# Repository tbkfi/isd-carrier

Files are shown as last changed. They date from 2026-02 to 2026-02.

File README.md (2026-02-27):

# Prototype PCB for International Sensor Development Project

This repository contains a schematic and pcb design for an international sensor development project between Metropolia UAS and Osnabrück Hochschule, which concluded on 2026.02.27.

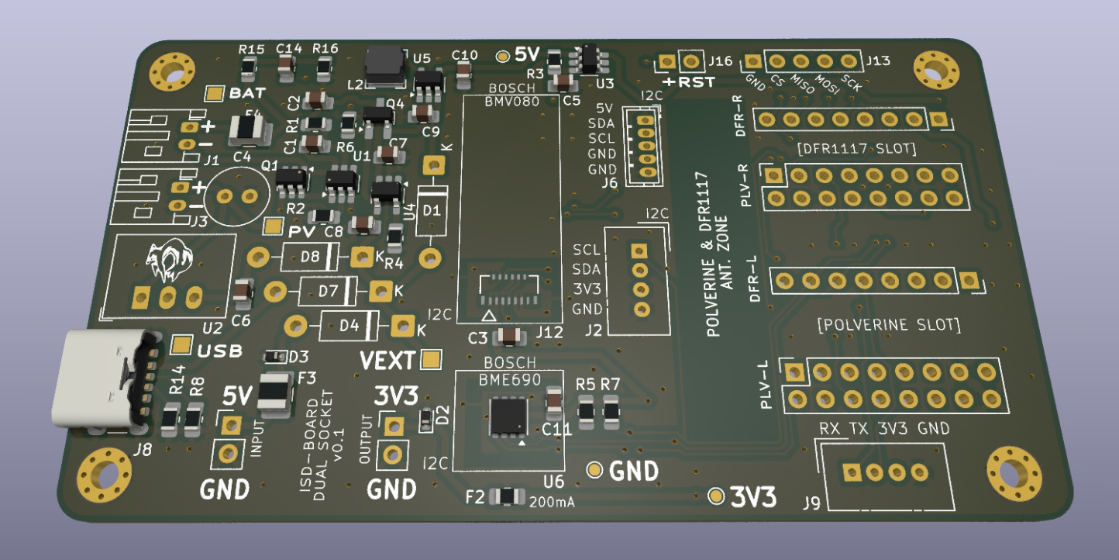
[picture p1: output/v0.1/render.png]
ISD Carrier Prototype PCB Render


## Board Features

The PCB provides 5V power to the MCU modules, which have built-in LDOs to provide 3V3 power
for external and integrated peripherals.

- Interleaved dual socket (BlackIoT Polverine and DFR1117)
- Built-in power switch (external reset/power button)
- LiPo protection circuit (2.4-4.2V)
- LiPo charging circuit (configurable output)
- Power Path management using P-FET, actuated by external power voltage to disconnect battery from load during charging.
- Auxiliary 3V3 output pin header.
- Multiple power input options (all selectively populatable):
	- JST(2.0mm): LiPo battery
	- JST(2.0mm): Photovoltaic panel (8-28V)
	- Header(2.54mm): E.g. Bench-top power supply
    - PCB USB-C (charging, 5V peripherals, main power)
	- (MCU module USB-C (no 5V peripherals, no charging!))
- Sensor support (for both Polverine & DFR1117):
	- BME690 via I2C (integrated, LGA, 3V3)
	- BMV080 via I2C (integrated, ZIF-connector, 3V3)*
	- Seeed E5 LoRa via UART (external, Grove, 3V3)
	- SPS30 via I2C (external, ZHR-5, 5V)
	- I2C (external, Grove, 3V3)
	- SPI (Header: CS, MISO, MOSI, SCK, GND)

## Documentation

See the repository directory labeled 'output' for the board revision files. The directory contains schematic (pdf), routing (png), and an interactive bill of materials (bom).

ISD Carrier Prototype PCB Schematic

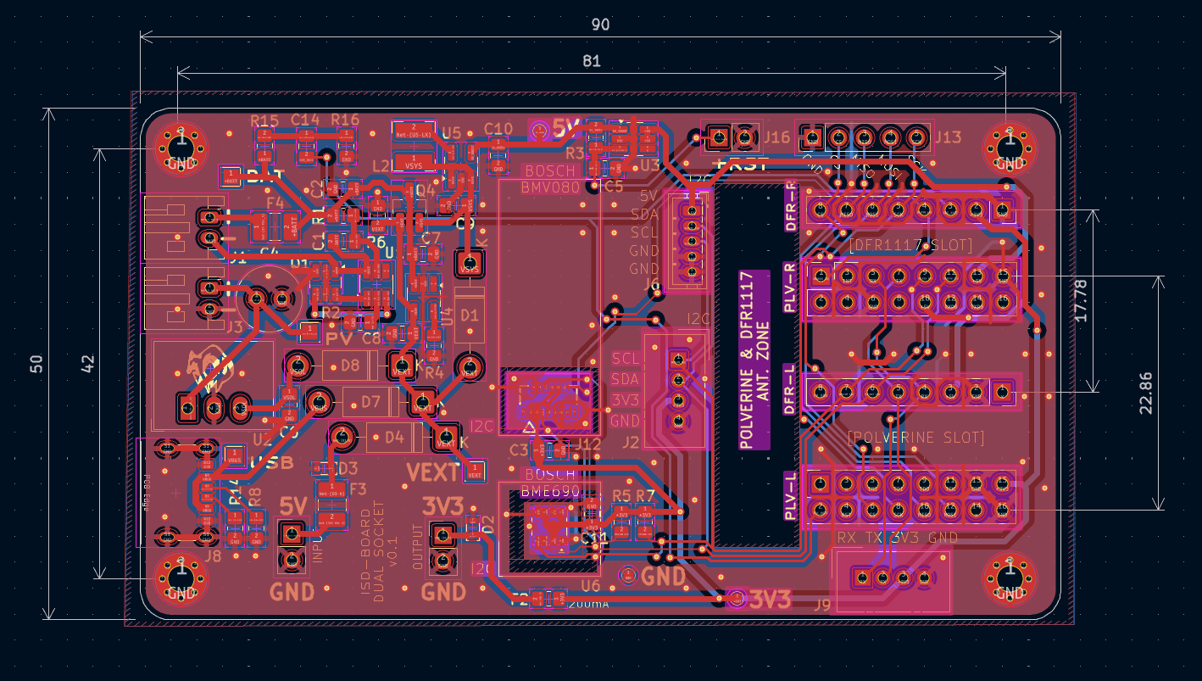
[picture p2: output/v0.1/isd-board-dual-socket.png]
ISD Carrier Prototype PCB Routing


### Issues

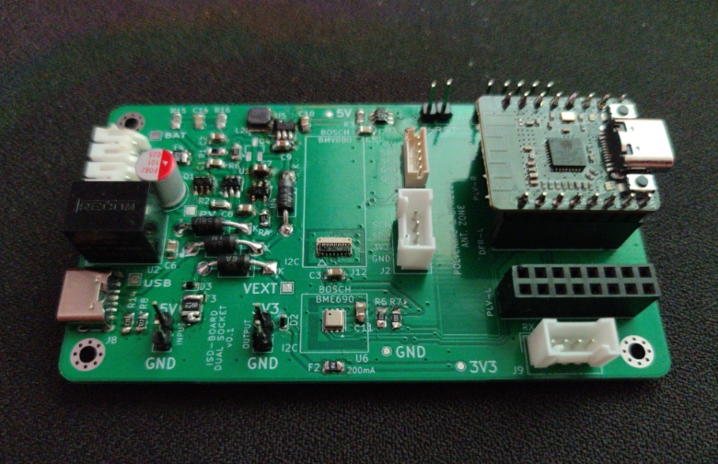
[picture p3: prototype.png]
Physical ISD Carrier Prototype PCB


This section contains issues encountered up to and during the final integration testing when using
this board with all the external peripherals. Some issues are PCB related, others are practical inefficiencies or overlooked details.

### version 0.1
1. ZIF-connector: Insertion direction is reversed. Causing the pin-direction to be flipped, making the connector unusable. Neccessitates the use of Polverine for BMV080 functionality.
2. Power Path: P-FET which was ordered had differing package type from original. Soldering was still possible at 45deg angle, and bending unneeded pins above the package to avoid shorts.
3. DW01A: Behaviour was unexpected during testing despite following datasheet application diagram in design. Couple workarounds were found, but ultimately the IC should be replaced in the design
with something more robust from TI or Microchip (E.g.) to increase reliability and control over the protection circuit.
4. Peripheral cabling: Operation was susceptible to jumpers, badly crimped or soldered cables, which caused unnecessary debugging and inconsistent results.
5. Prototype PCB count: Not enough prototypes were made to provide such large teams with an efficient number of PCBs while continuing to validate power management behaviour.
As LoRa and Sensor teams received one prototype, and found them to be in working condition, it became virtually impossible to get either of them back for more power-related validation. 
6. It's a good idea to validate the MCU modules and cabling that is in use by other teams, specially if they were made or modified by them, as on more than one ocassion incorrectly (or not at all)
soldered pin headers caused certain functionality to not work, as nothing was plugged in...
7. I2C Pull-ups: Existing 10k pulls caused issues with DFR1117, while the configuration worked with Polverine. The pull-ups on PCB were removed to fix the issue. Though it's possible
this issue was due to bad cabling or bad sensor, as the pull-ups shouldn't technically cause this kind of issue in this configuration.

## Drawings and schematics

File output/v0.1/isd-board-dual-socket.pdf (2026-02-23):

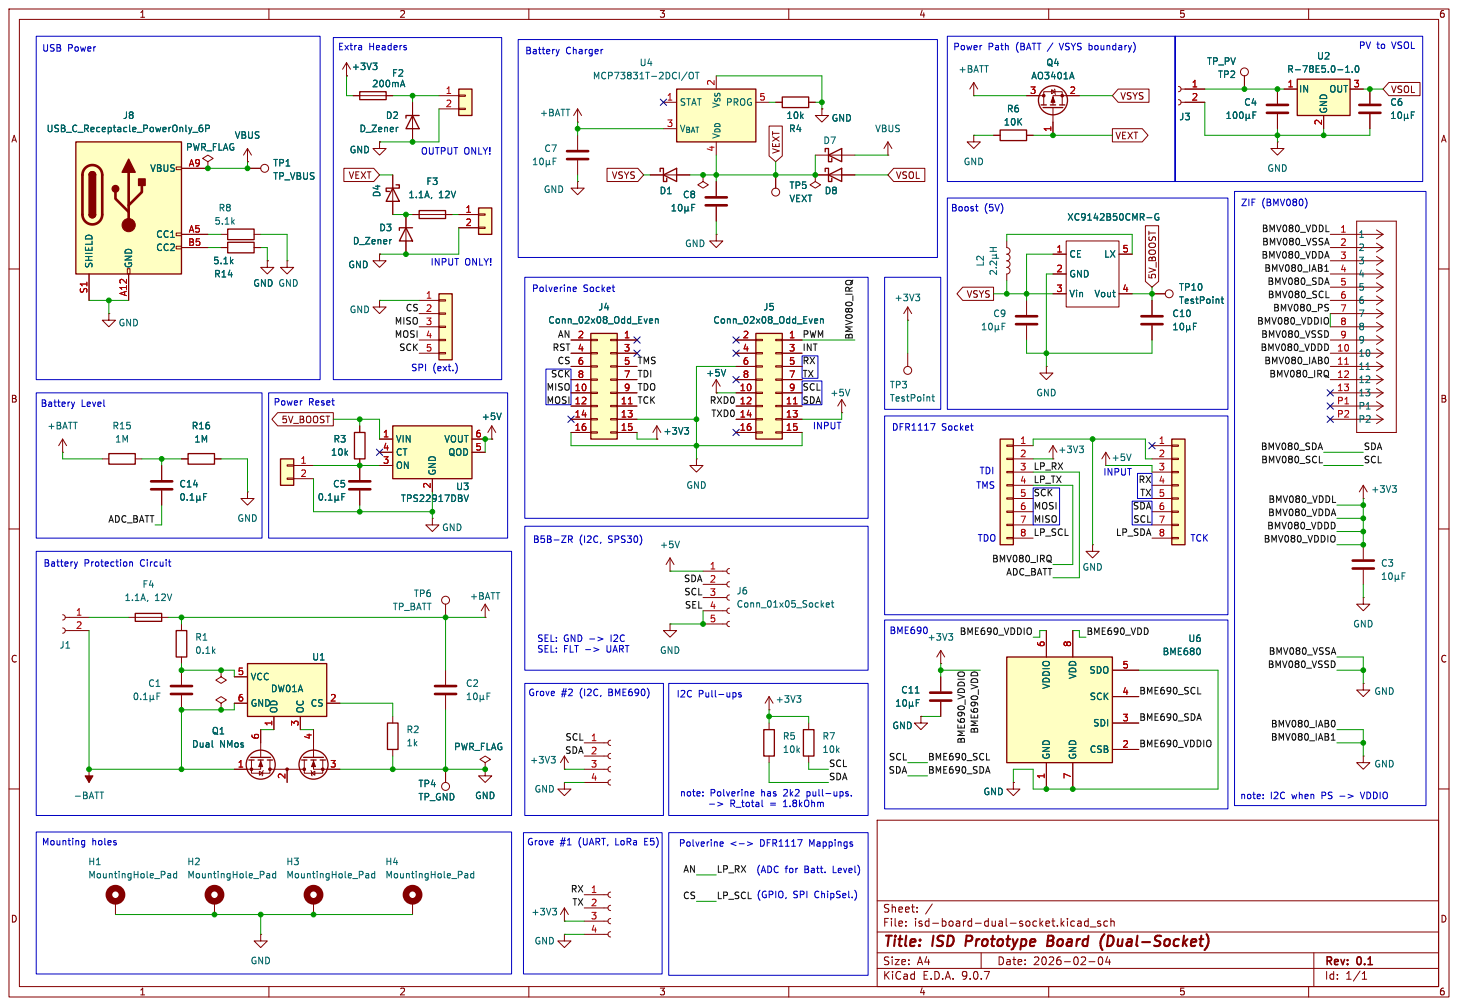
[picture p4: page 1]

7 SDO 5 SCK 4 SDI 3 CSB 2 U6 BME680 GND GND GND

7 SDO 5 SCK 4 SDI 3 CSB 2 GND

(ADC for Batt. Level)

Id: 1/1 Title: ISD Prototype Board (Dual-Socket) File: isd-board-dual-socket.kicad_sch Sheet: /

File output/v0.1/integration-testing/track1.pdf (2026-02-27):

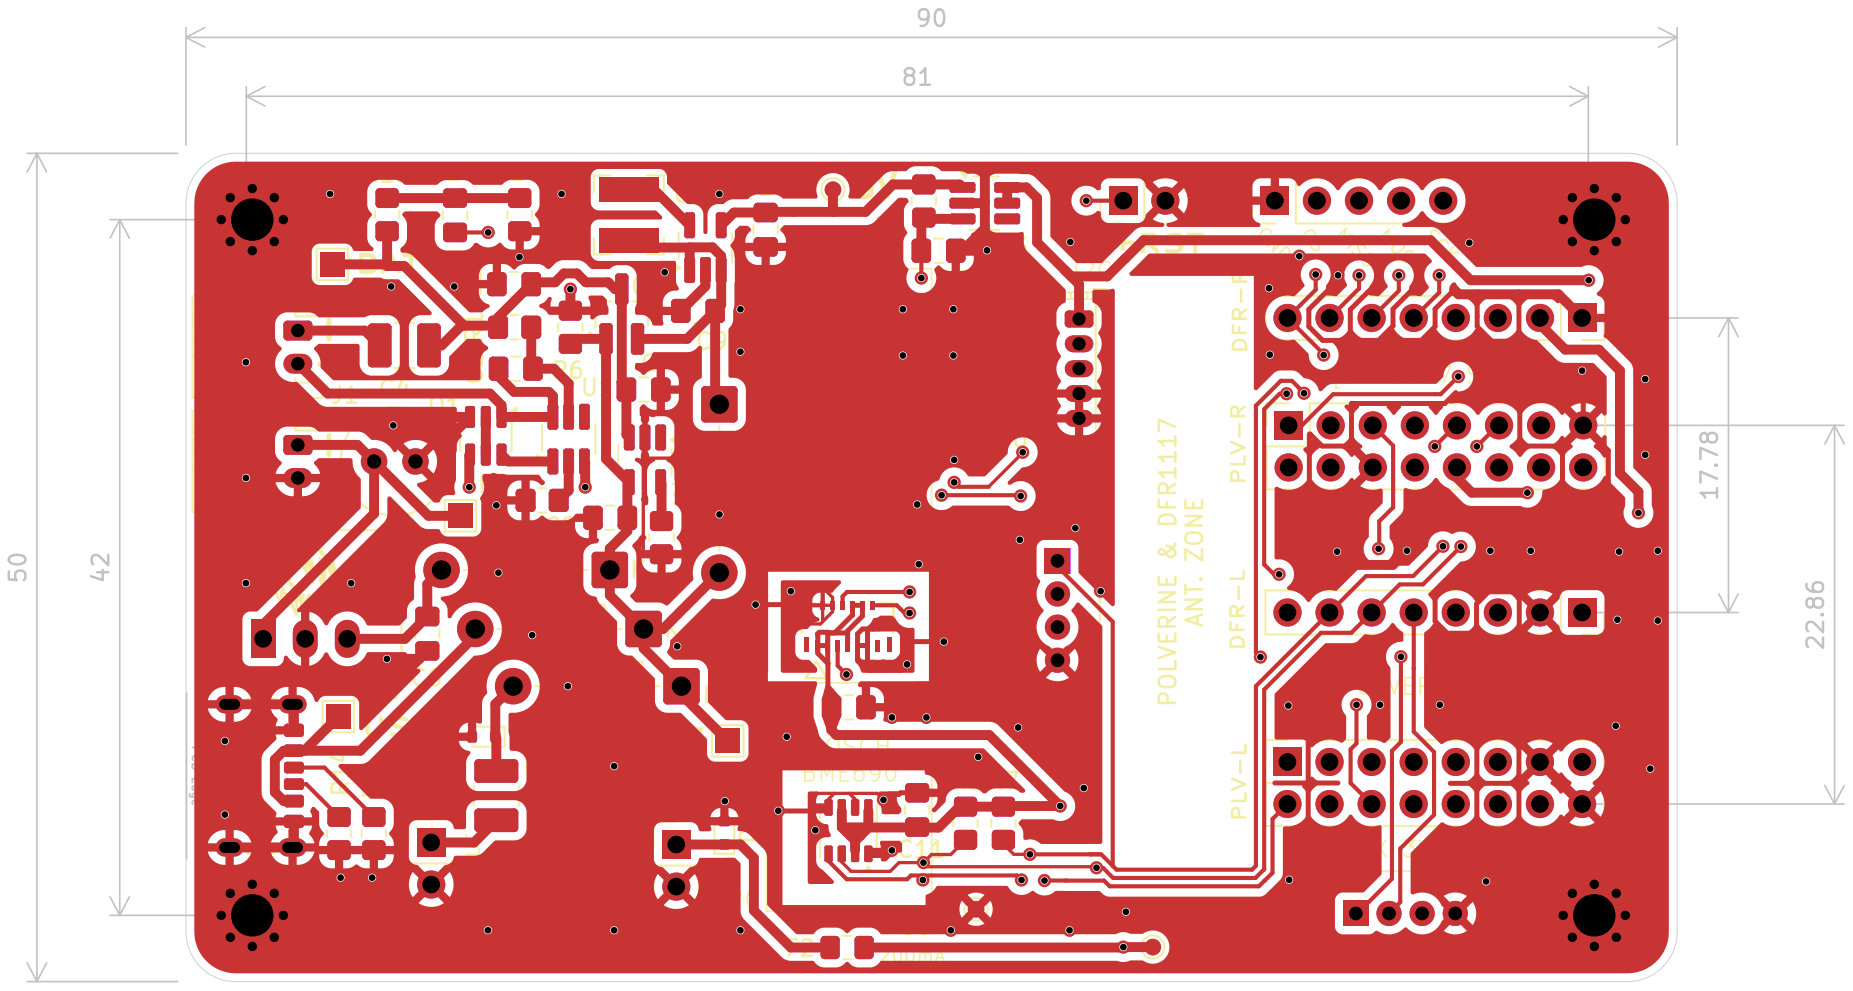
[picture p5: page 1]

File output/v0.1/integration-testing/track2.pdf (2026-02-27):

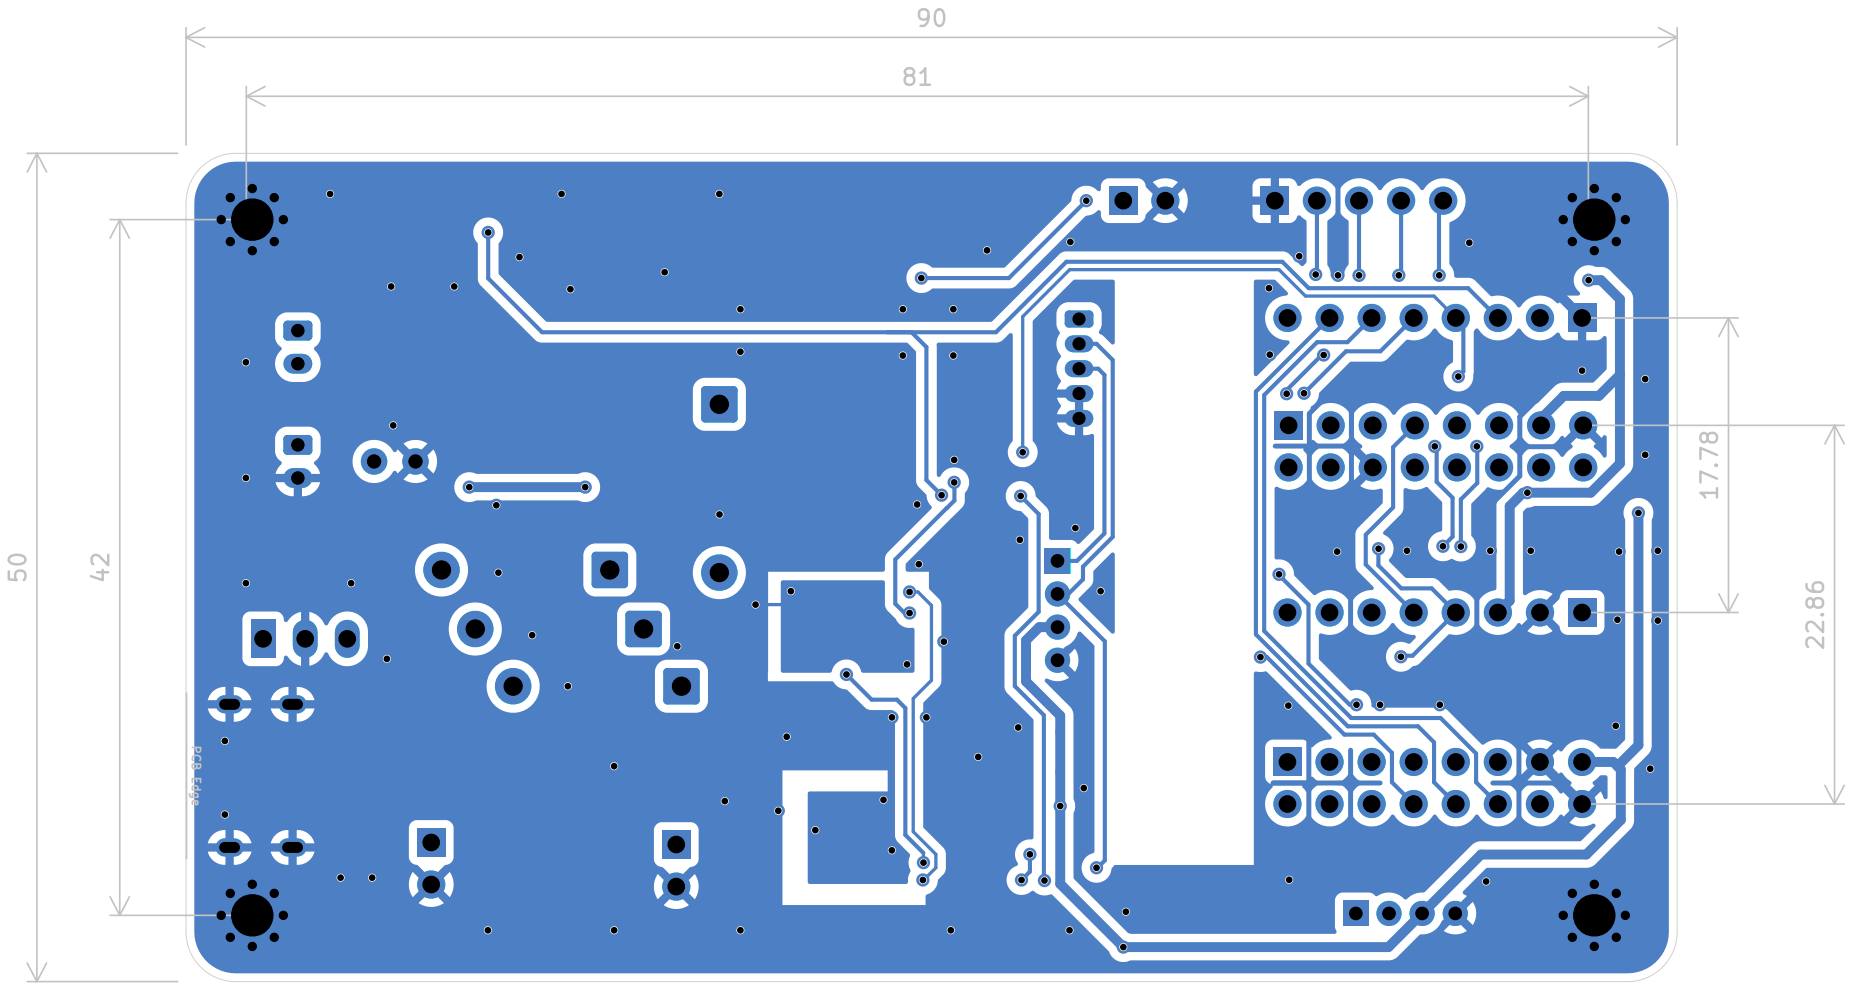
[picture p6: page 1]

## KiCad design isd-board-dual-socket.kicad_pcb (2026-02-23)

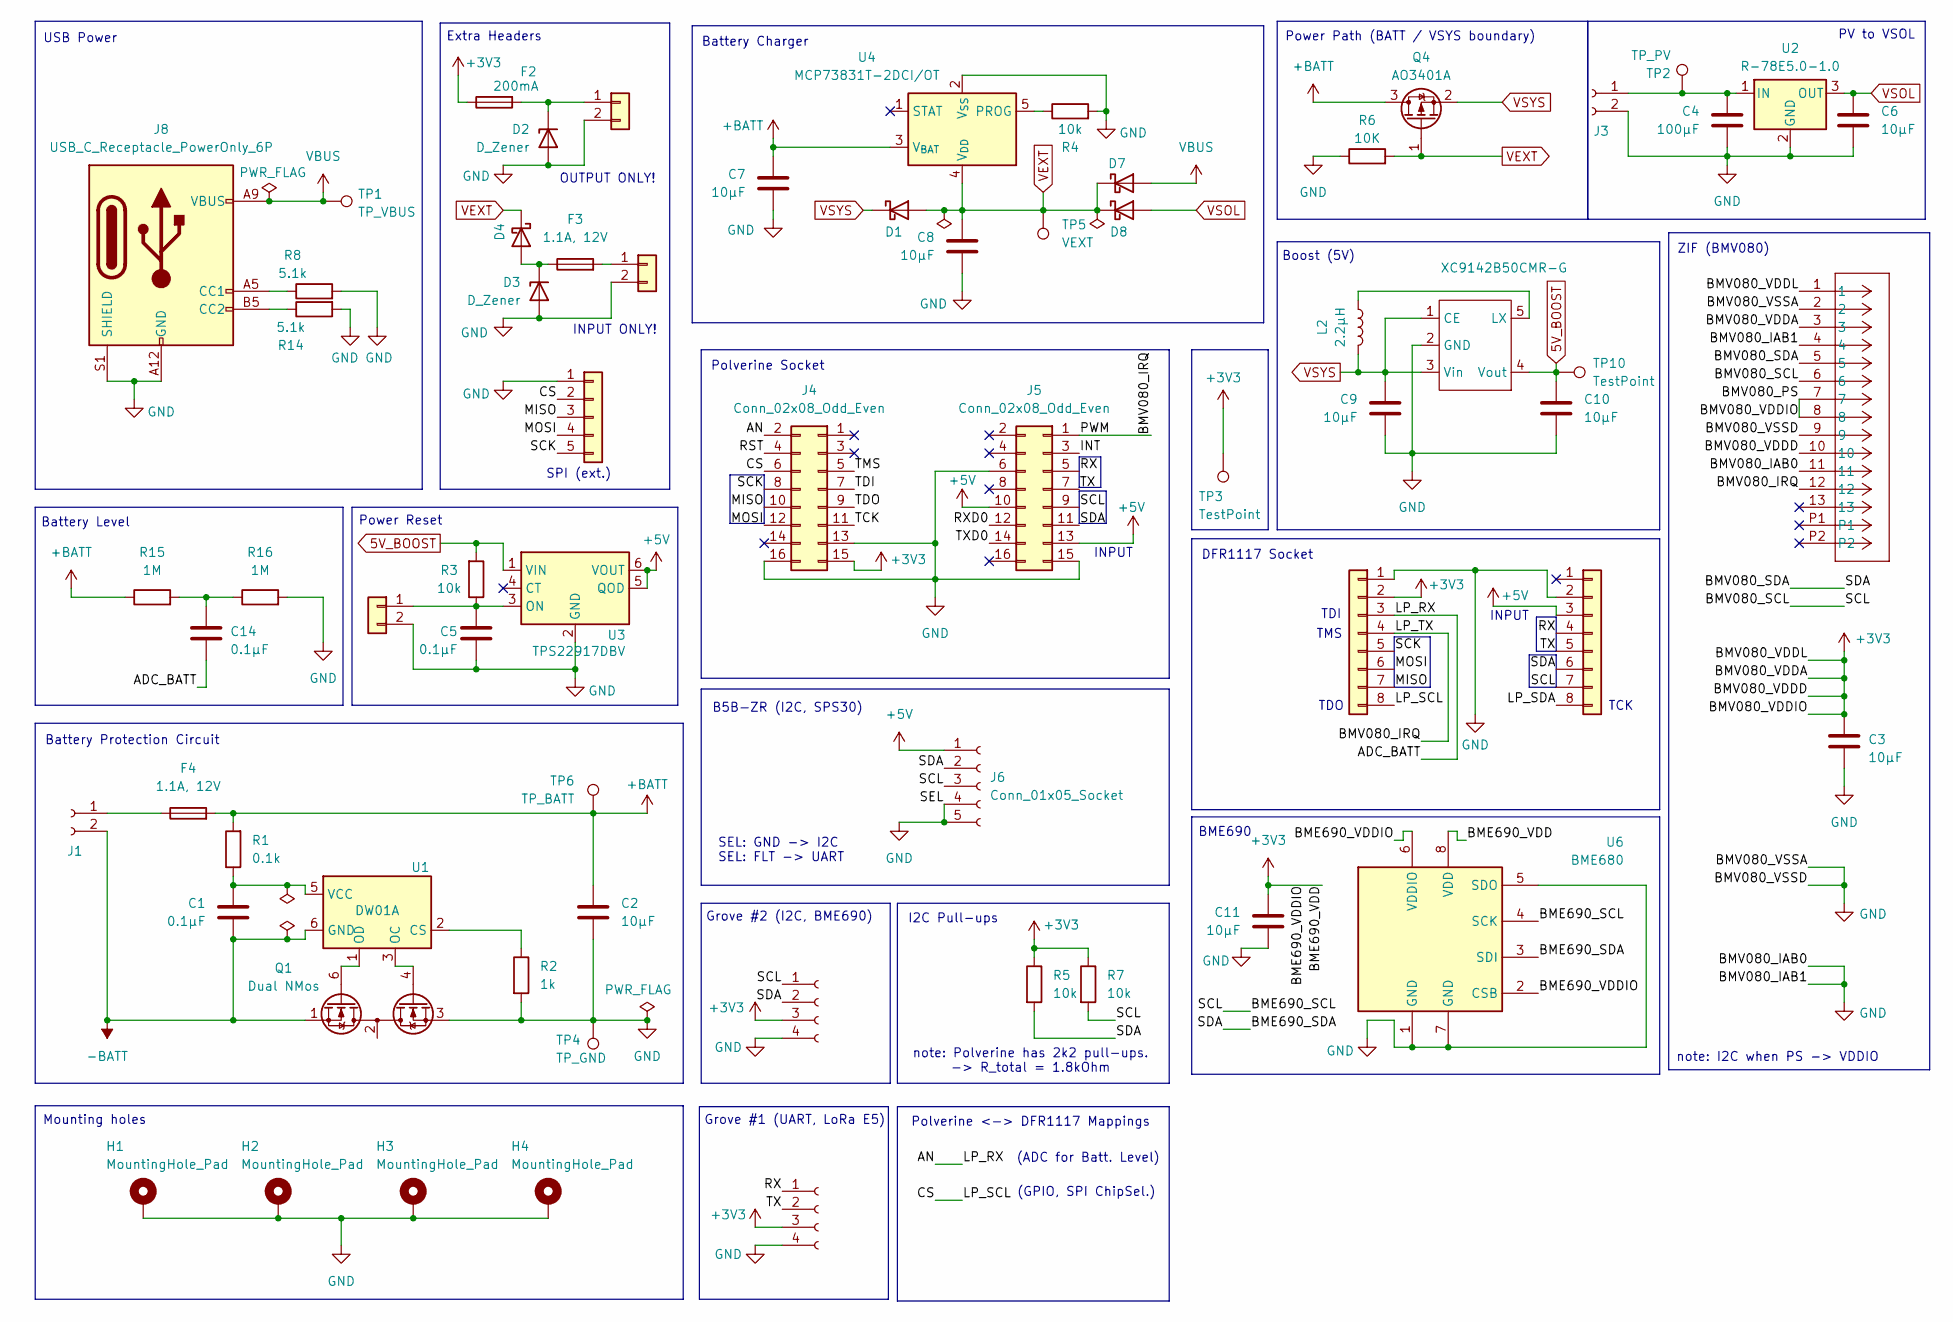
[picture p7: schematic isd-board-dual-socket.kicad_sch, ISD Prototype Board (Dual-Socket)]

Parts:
C1, C5, C14: 0.1µF; C_0805_2012Metric_Pad1.18x1.45mm_HandSolder; MPN 399-C0805C104K5RACTUCT-ND
C2, C3, C6, C7, C8, C9, C10, C11: 10µF; C_0805_2012Metric_Pad1.18x1.45mm_HandSolder; MPN GRM21BR61E106KA73K
C4: 100µF; C_Radial_D6.3mm_H11.0mm_P2.50mm; MPN RPF0608101M035K
D1, D4, D7, D8: D_Schottky; D_DO-41_SOD81_P10.16mm_Horizontal; MPN 1655-1N5817CT-ND
D2, D3: D_Zener; D_SOD-523; MPN CPDH5V0U
F2: 200mA; Fuse_0805_2012Metric_Pad1.15x1.40mm_HandSolder; MPN SMD0805B020TF
F3, F4: 1.1A, 12V; Fuse_1210_3225Metric_Pad1.42x2.65mm_HandSolder; MPN SMD1210B110TF
H1, H2, H3, H4: MountingHole_Pad; MountingHole_2.5mm_Pad_Via; MPN none
J1, J3: Conn_01x02_Socket; JST_PH_S2B-PH-K_1x02_P2.00mm_Horizontal; MPN 455-1719-ND
J2, J9: Conn_01x04_Socket; NS-Tech_Grove_1x04_P2mm_Vertical; MPN 1597-1082-ND
J4, J5: Conn_02x08_Odd_Even; PinSocket_2x08_P2.54mm_Vertical; MPN 732-61301621821-ND
J6: Conn_01x05_Socket; JST_ZH_B5B-ZR_1x05_P1.50mm_Vertical; MPN B5B-ZR
J7, J10: Conn_01x08; PinSocket_1x08_P2.54mm_Vertical; MPN PPTC081LFBN-RC
J8: USB_C_Receptacle_PowerOnly_6P; USB_C_Receptacle_GCT_USB4125-xx-x-0190_6P_TopMnt_Horizontal; MPN USB4125-GF-A
J12: 5035661302; CON_5035661302_MOL; MPN 046844713002846+
J13: Conn_01x05; PinHeader_1x05_P2.54mm_Vertical; MPN ???
J14, J15, J16: Conn_01x02; PinHeader_1x02_P2.54mm_Vertical; MPN 61300211121
L2: 2.2µH; L_Bourns-SRN4018; MPN SRN4018-2R2M
Q1: Dual NMos; SOT-23-6; MPN DMG9926UDMDICT-ND
Q4: AO3401A; SOT-23_Handsoldering; MPN AO3401A
R1: 0.1k; R_0805_2012Metric_Pad1.20x1.40mm_HandSolder; MPN 541-100CCT-ND
R2: 1k; R_0805_2012Metric_Pad1.20x1.40mm_HandSolder; MPN 10-ERJ-HP6J102VCT-ND
R3, R4, R5, R7: 10k; R_0805_2012Metric_Pad1.20x1.40mm_HandSolder; MPN 541-4163-1-ND
R6: 10K; R_0805_2012Metric_Pad1.20x1.40mm_HandSolder; MPN 541-4163-1-ND
R8, R14: 5.1k; R_0805_2012Metric_Pad1.20x1.40mm_HandSolder; MPN 311-5.1KARCT-ND
R15, R16: 1M; R_0805_2012Metric_Pad1.20x1.40mm_HandSolder; MPN 408-RG2012P-105-B-T5CT-ND
TP1: TP_VBUS; TestPoint_Pad_1.5x1.5mm; MPN none
TP2: TP_PV; TestPoint_Pad_1.5x1.5mm; MPN none
TP3, TP10: TestPoint; TestPoint_Pad_D1.0mm; MPN none
TP4: TP_GND; TestPoint_Pad_D1.0mm; MPN none
TP5: VEXT; TestPoint_Pad_1.5x1.5mm; MPN none
TP6: TP_BATT; TestPoint_Pad_1.5x1.5mm; MPN none
U1: DW01A; SOT-23-6_Handsoldering; MPN DW01A
U2: R-78E5.0-1.0; Converter_DCDC_RECOM_R-78E-0.5_THT; MPN R-78E5.0-1.0
U3: TPS22917DBV; SOT-23-6_Handsoldering; MPN TPS22917DBV
U4: MCP73831T-2DCI/OT; SOT-23-5_HandSoldering; MPN MCP73831T-2DCI/OT
U5: XC9142B50CMR-G; SOT-23-5_HandSoldering; MPN XC9142B50CMR-G
U6: BME680; Bosch_LGA-8_3x3mm_P0.8mm_ClockwisePinNumbering; MPN BME690

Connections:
5V_BOOST: C10.1, R3.2, TP10.1, U3.1 (VIN), U5.4 (Vout)
+3V3: C3.1, C11.1, F2.1, J2.3, J4.15, J9.3, J10.2, J12.1, J12.3, J12.7, J12.8, J12.10, R5.1, R7.1, TP3.1, U6.2 (CSB), U6.6 (VDDIO), U6.8 (VDD)
+5V: J5.10, J5.13, J6.1, J7.3, U3.5 (QOD), U3.6 (VOUT)
+BATT: C2.1, C7.1, F4.2, Q4.3 (D), R1.2, R15.1, TP6.1, U4.3 (V_{BAT})
-BATT: C1.2, J1.2, Q1.1 (D1), U1.6 (GND)
/ADC_BATT: C14.2, J4.2, J10.3
/BME690_SCL: J2.1, J5.9, J6.3, J7.7, J12.6, R7.2, U6.4 (SCK)
/BME690_SDA: J2.2, J5.11, J6.2, J7.6, J12.5, R5.2, U6.3 (SDI)
/BMV080_IRQ: J5.1, J10.4, J12.12
/CS: J4.6, J10.8, J13.2
/INT: J5.3
/LP_SDA: J7.8
/MISO: J4.10, J10.7, J13.3
/MOSI: J4.12, J10.6, J13.4
/RST: J4.4
/RX: J5.5, J7.4, J9.1
/RXD0: J5.12
/SCK: J4.8, J10.5, J13.5
/TCK: J4.11
/TDI: J4.7
/TDO: J4.9
/TMS: J4.5
/TX: J5.7, J7.5, J9.2
/TXD0: J5.14
GND: C2.2, C3.2, C4.2, C5.2, C6.2, C7.2, C8.2, C9.2, C10.2, C11.2, D2.2 (A), D3.2 (A), H1.1, H2.1, H3.1, H4.1, J2.4, J3.2, J4.13, J4.16, J5.6, J5.15, J6.4, J6.5, J7.2, J8.A12 (GND), J8.B12 (GND), J8.S1 (SHIELD), J9.4, J10.1, J12.2, J12.4, J12.9, J12.11, J13.1, J14.2, J15.2, J16.2, Q1.3 (S2), R2.2, R4.2, R6.1, R8.2, R14.2, R16.2, TP4.1, U2.2 (GND), U3.2 (GND), U4.2 (V_{SS}), U5.2 (GND), U6.1 (GND), U6.5 (SDO), U6.7 (GND)
unnamed: C14.1, R15.2, R16.1
unnamed: D2.1 (K), F2.2, J14.1
unnamed: D3.1 (K), D4.2 (A), F3.1
unnamed: F4.1, J1.1
unnamed: C4.1, J3.1, TP2.1, U2.1 (IN)
unnamed: J8.A5 (CC1), R8.1
unnamed: J8.B5 (CC2), R14.1
unnamed: F3.2, J15.1
unnamed: C5.1, J16.1, R3.1, U3.3 (ON)
unnamed: Q1.6 (G1), U1.1 (OD)
unnamed: Q1.4 (G2), U1.3 (OC)
unnamed: Q1.2 (S1/D2), Q1.5 (S1/D2)
unnamed: R2.1, U1.2 (CS)
unnamed: C1.1, R1.1, U1.5 (VCC)
unnamed: R4.1, U4.5 (PROG)
unnamed: L2.2, U5.5 (LX)
VBUS: D7.2 (A), J8.A9 (VBUS), J8.B9 (VBUS), TP1.1
VEXT: C8.1, D1.2 (A), D4.1 (K), D7.1 (K), D8.1 (K), Q4.1 (G), R6.2, TP5.1, U4.4 (V_{DD})
VSOL: C6.1, D8.2 (A), U2.3 (OUT)
VSYS: C9.1, D1.1 (K), L2.1, Q4.2 (S), U5.1 (CE), U5.3 (Vin)

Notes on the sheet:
INPUT
B5B-ZR (I2C, SPS30)
Polverine Socket
TDO
I2C Pull-ups
PV to VSOL
Battery Level
OUTPUT ONLY!
Power Reset
INPUT ONLY!
note: Polverine has 2k2 pull-ups. -> R_total = 1.8kOhm
DFR1117 Socket
Mounting holes
TDI
BME690
(GPIO, SPI ChipSel.)
Boost (5V)
TCK
Power Path (BATT / VSYS boundary)
Extra Headers
(ADC for Batt. Level)
Battery Charger
ZIF (BMV080)
Grove #1 (UART, LoRa E5)
SPI (ext.)
note: I2C when PS -> VDDIO
Battery Protection Circuit
Polverine <-> DFR1117 Mappings
TMS
USB Power
SEL: GND -> I2C SEL: FLT -> UART
Grove #2 (I2C, BME690)

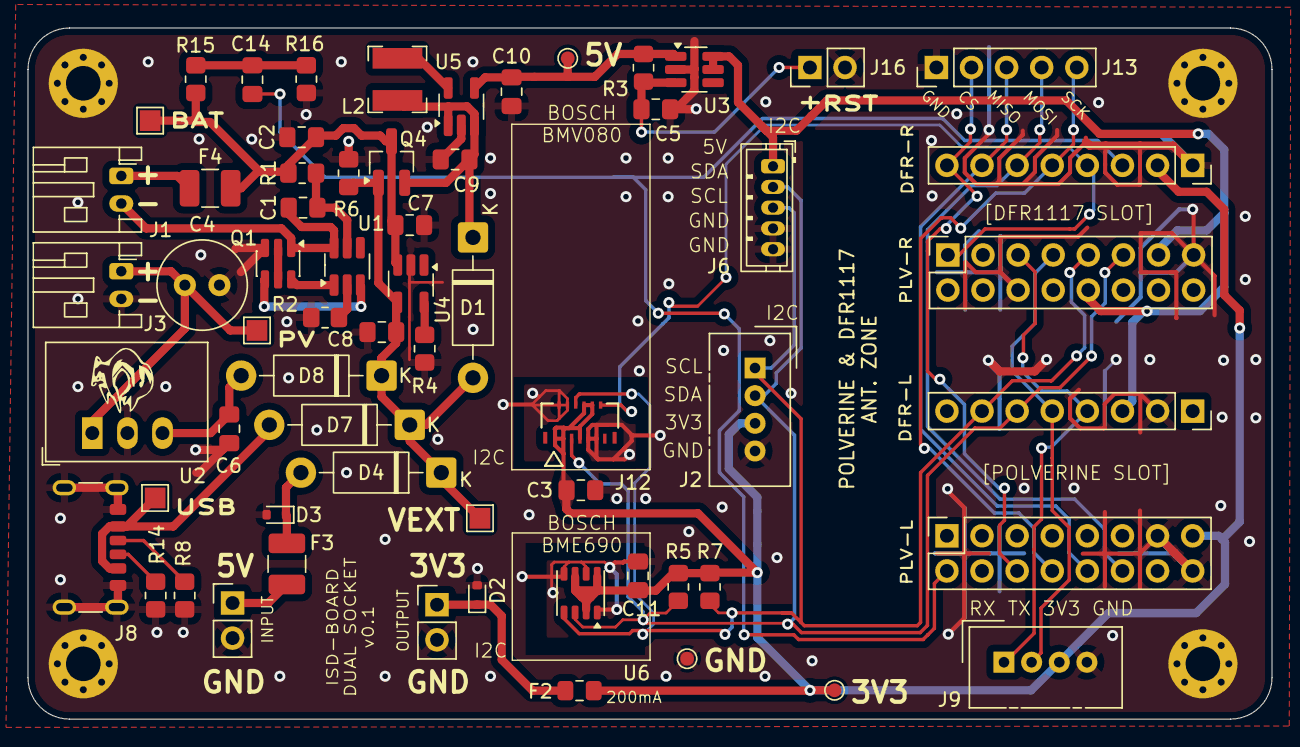
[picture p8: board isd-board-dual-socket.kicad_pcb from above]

Board: 2 copper layers, 90.0 x 50.0 mm, 67 parts (0 on the bottom side), 36 nets.

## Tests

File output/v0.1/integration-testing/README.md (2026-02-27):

These files were printed out during integration testing to make information on routing and components
easily accessible to sensor and lora teams.

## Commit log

2026-02-23 add: version 0.1
    [isd-board-dual-socket-B_Cu.gbl, isd-board-dual-socket-B_Mask.gbs, isd-board-dual-socket-B_Paste.gbp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]
2026-02-25 update: prototype image, track issues in README.md
